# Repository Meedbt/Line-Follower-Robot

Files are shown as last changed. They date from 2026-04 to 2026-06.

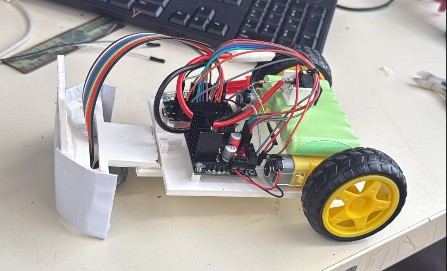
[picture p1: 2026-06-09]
RobotZEBI/assets/robot.jpg

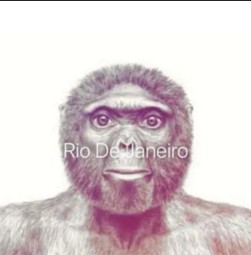
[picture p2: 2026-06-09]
RobotZEBI/assets/photoequipe.jpg

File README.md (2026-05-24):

# 🤖 Line Follower Robot — GEII BUT1

Robot autonome suiveur de ligne développé dans le cadre des **Rencontres de Robotique BUT GEII 2026** .

Projet réalisé en 1ère année de BUT GEII, en équipe de 3 étudiants.

## Matériel utilisé
- **Microcontrôleur :** ESP32
- **Capteur de ligne :** Pololu QTR-8A (8 capteurs IR)
- **Hacheur moteur :** L298N (Joy-IT SBC-MotoDriver2)
- **Moteurs :** 2× moteurs DC TT + roue folle
- **Détection barrière :** Capteur ultrason HC-SR04
- **Alimentation :** Batterie 12V

## Fonctionnalités
- Suivi de ligne par algorithme PID
- Interface web via Wi-Fi pour régler les paramètres PID en temps réel
- Gestion des lignes en pointillés et segments inversés (blanc sur noir)
- Arrêt automatique à l'arrivée via l'ultrason
- Marche arrière gérée

## Châssis
- Style châssis RC, cadre ouvert
- Imprimé en 3D (PLA), modélisé sur Fusion 360

## 1. Schéma de câblage


Capture d’écran 2026-04-15 215151

## 2. Modele 3D 


---
*IUT — BUT GEII 1ère année | Rencontres Robotique 2026*

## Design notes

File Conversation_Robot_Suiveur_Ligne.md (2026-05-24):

# Conversation Complete - Robot Suiveur De Ligne ESP32

Ce document resume toute la conversation et l'evolution du projet de robot suiveur de ligne: materiel, logique de suivi, interface, marqueurs, intersections, ultrason, batterie, challenges, parcours avance et nouvelle interface competition.

## 1. Materiel Et Objectif

Le projet principal utilise:

- ESP32
- QTR-8RC
- L298N
- deux moteurs DC
- capteur ultrason HC-SR04
- batterie NiMH 7.2V
- interface web embarquee

Objectif:

- suivre une ligne noire sur fond clair
- executer des challenges de robotique
- gerer les marqueurs et intersections
- detecter l'arrivee/barriere
- automatiser les missions via une interface simple

## 2. Code De Reference Initial

Le code de reference fourni au debut utilisait:

- `AFMotor.h`
- `QTRSensors.h`
- 5 capteurs
- un controleur PD

Principe du code original:

```cpp
position = qtrrc.readLine(sensors);
error = position - 2000;

motorSpeed = KP * error + KD * (error - lastError);
lastError = error;

leftMotorSpeed = baseSpeed + motorSpeed;
rightMotorSpeed = baseSpeed - motorSpeed;
```

Il ne pouvait pas etre repris directement car il etait fait pour un shield moteur Adafruit, pas pour un ESP32 avec L298N.

## 3. Pins Actuelles

Pins QTR-8RC, dans l'ordre physique gauche vers droite:

```cpp
const uint8_t BROCHES_CAPTEURS[NOMBRE_CAPTEURS] = {
  18, 25, 33, 32, 5, 4, 22, 23
};
```

Pins L298N:

```cpp
const uint8_t PWM_GAUCHE = 16;
const uint8_t GAUCHE_IN1 = 26;
const uint8_t GAUCHE_IN2 = 27;
const uint8_t PWM_DROITE = 19;
const uint8_t DROITE_IN1 = 14;
const uint8_t DROITE_IN2 = 12;
```

Pins ultrason:

```cpp
const uint8_t ULTRASON_TRIG = 21;
const uint8_t ULTRASON_ECHO = 13;
```

Pin batterie:

```cpp
const uint8_t BATTERIE_ADC = 35;
```

Notes importantes:

- GPIO34 et GPIO35 ne doivent pas etre utilises pour le QTR-8RC car ils sont entree uniquement.
- GPIO35 est par contre tres bien pour mesurer la batterie.
- Si le HC-SR04 est alimente en 5V, il faut un diviseur de tension sur `ECHO`.

## 4. Suivi De Ligne

La version ESP32 utilise:

```cpp
qtr.readLineBlack(valeursCapteurs);
```

Donc:

```text
0    = blanc
1000 = noir
```

Position:

```text
0    = ligne tout a gauche
3500 = ligne au centre
7000 = ligne tout a droite
```

Controle PD:

```cpp
erreur = position - 3500;
derivee = erreur - derniereErreur;
correction = kp * erreur + kd * derivee;

vitesseGauche = vitesseBase + correction;
vitesseDroite = vitesseBase - correction;
```

Reglages principaux:

```cpp
int vitesseBase = 135;
float kp = 0.075;
float kd = 0.45;
```

Reglage:

```text
Robot trop lent en virage  -> augmenter KP
Robot zigzague             -> augmenter KD ou baisser KP
Robot stable mais lent     -> augmenter vitesseBase
```

## 5. Ancienne Interface Web De Reglage

Une premiere interface web complete avait ete creee.

Elle permettait de regler:

- vitesse base
- KP
- KD
- mode arret marqueur
- nombre de marqueurs avant stop
- stop ultrason
- distance stop ultrason
- mode intersections
- sequence intersections
- parcours avance
- sequence aller
- sequence retour
- demi-tour apres marqueur/intersection
- pauses parking B/C
- arret final marqueur/intersection

Elle affichait:

- position
- erreur
- vitesses moteurs
- capteurs QTR
- marqueurs
- intersections
- ultrason
- batterie
- phase
- action

L'option `Correction inversee` a ete supprimee car elle ne servait pas.

## 6. Nouvelle Interface Competition

Une nouvelle interface simplifiee a ete creee pour le jour du challenge.

Elle remplace l'affichage de l'ancienne interface:

```cpp
serveur.send_P(200, "text/html", PAGE_COMPETITION);
```

L'ancienne interface `PAGE_WEB` est encore dans le code comme sauvegarde interne, mais elle n'est plus affichee.

Nouvelle interface:

- selection du challenge
- bouton `CALIBRER`
- bouton `START CHALLENGE`
- bouton `URGENCE STOP`
- challenge actif
- position ligne
- ultrason barriere
- batterie
- priorite droite
- marqueurs
- intersections
- phase
- etape/action actuelle

Wi-Fi:

```text
Nom : Robot Z.E.B.I
Mot de passe : 12345678
Adresse : http://192.168.4.1
```

## 7. Profils De Challenges

Les challenges sont maintenant pre-codes dans:

```cpp
const ChallengeConfig CHALLENGES[] = { ... };
```

Chaque challenge contient:

- nom
- arret marqueur oui/non
- cible marqueur
- stop ultrason oui/non
- distance stop
- mode intersections oui/non
- sequence simple
- parcours avance oui/non
- sequence aller
- sequence retour
- demi-tour apres marqueur
- demi-tour apres intersection
- pause B apres marqueur
- pause C apres marqueur
- arret final apres marqueur
- arret final apres intersection

Quand un challenge est selectionne:

```cpp
appliquerChallenge(numeroChallenge);
```

Le robot charge automatiquement la configuration correspondante.

## 8. Marqueurs Lateraux

Les petits tires noirs sur les cotes sont traites comme des marqueurs.

Capteurs utilises:

```text
valeursCapteurs[0] et [1] = cote gauche
valeursCapteurs[6] et [7] = cote droit
```

Un marqueur est compte si:

- le centre voit encore la ligne
- un capteur extreme voit du noir
- ce n'est pas une intersection
- le robot est actif
- le marqueur n'a pas deja ete compte

Le code evite de compter plusieurs fois le meme marqueur avec:

```cpp
marqueurDejaCompte
DELAI_ANTI_DOUBLE_MS
```

## 9. Difference Entre Marqueur Et Intersection

La difference se fait avec le nombre de capteurs noirs.

Marqueur:

```text
centre noir + extreme noir + peu de capteurs noirs
```

Intersection:

```text
beaucoup de capteurs noirs en meme temps
```

Seuil:

```cpp
const uint8_t NB_CAPTEURS_NOIRS_INTERSECTION = 5;
```

Donc:

```text
moins de 5 capteurs noirs -> possible marqueur
5 capteurs noirs ou plus  -> intersection, pas marqueur
```

## 10. Mode Arret Marqueur

Ce mode sert aux challenges ou le robot doit s'arreter a un endroit demande.

Principe:

```text
Mode arret marqueur = Oui
Marqueurs avant stop = N
Quand compteurMarqueurs >= N -> stop
```

En mode parcours avance, cet arret simple est ignore pour ne pas bloquer les aller-retour:

```cpp
if (modeArretMarqueur && !modeParcoursAvance && compteurMarqueurs >= cibleMarqueurs)
```

## 11. Ultrason Et Barriere

Le capteur ultrason detecte les barres d'arrivee.

Pins:

```cpp
const uint8_t ULTRASON_TRIG = 21;
const uint8_t ULTRASON_ECHO = 13;
```

Principe:

```text
Stop ultrason = Oui
Distance <= distanceStop
pendant 3 mesures d'affilee
=> stop
```

Pour faire tomber une barriere:

```text
Stop ultrason = Non
```

Pour eviter la barriere:

```text
Stop ultrason = Oui
Distance stop = environ 10 a 20 cm
```

## 12. Batterie NiMH 7.2V

La batterie est une NiMH 7.2V.

Tensions:

```text
pleine  : 8.4V
nominale: 7.2V
faible  : 6.0V
```

Montage pont diviseur:

```text
+ batterie
   |
  R1 = 100k
   |
   +---- GPIO35 ESP32
   |
  R2 = 47k
   |
GND batterie / GND ESP32
```

Constantes:

```cpp
const float BAT_R1 = 100000.0;
const float BAT_R2 = 47000.0;
const float BAT_TENSION_MAX = 8.4;
const float BAT_TENSION_MIN = 6.0;
const float BAT_CALIBRATION = 1.00;
```

Si l'affichage ne correspond pas au multimetre, ajuster:

```cpp
BAT_CALIBRATION
```

## 13. Gestion Des Intersections

Le mode intersections permet d'utiliser une sequence de decisions.

Lettres:

```text
S = tout droit
G = gauche
D = droite
```

Exemples valides:

```text
SSG
S,S,G
S D G
```

Le code nettoie automatiquement la sequence et ne garde que `S`, `G`, `D`.

Exemple:

```text
Sequence = SSG
```

Signifie:

```text
intersection 1 -> tout droit
intersection 2 -> tout droit
intersection 3 -> gauche
```

Si le robot voit plus d'intersections que la sequence, il repete la derniere decision.

Exemple:

```text
S,D
```

Donne:

```text
intersection 1 -> S
intersection 2 -> D
intersection 3 -> D
intersection 4 -> D
```

## 14. Parcours Avance

Le mode parcours avance sert pour les missions avec:

- aller
- demi-tour
- retour
- pauses parking
- arret final

Reglages:

```text
Parcours avance
Sequence aller
Sequence retour
Demi-tour apres marqueur
Demi-tour apres intersection
Pause B apres marqueur
Pause C apres marqueur
Arret final marqueur
Arret final intersection
```

Valeur `0`:

```text
desactive la fonction
```

## 15. Sequence Aller / Retour

Si:

```text
Parcours avance = Oui
Sequence aller = SSG
Sequence retour = vide
```

Alors la sequence retour est automatiquement nettoyee et devient:

```text
S
```

Mais le robot ne passe en phase retour que si un demi-tour est defini:

```text
Demi-tour apres marqueur > 0
ou
Demi-tour apres intersection > 0
```

Sans demi-tour, le robot reste en phase `Aller`.

## 16. Demi-Tour

Deux facons de declencher le demi-tour:

```text
Demi-tour apres marqueur
Demi-tour apres intersection
```

Exemple:

```text
Sequence aller = SSG
Demi-tour apres intersection = 3
Demi-tour apres marqueur = 0
```

Le robot:

```text
intersection 1 -> S
intersection 2 -> S
intersection 3 -> G
puis demi-tour
passe en phase Retour
```

Utiliser:

```text
Demi-tour apres intersection
```

si le point de demi-tour est lie a un croisement.

Utiliser:

```text
Demi-tour apres marqueur
```

si le point de demi-tour est lie a un petit tire lateral.

## 17. Arret Final

Les options:

```text
Arret final marqueur
Arret final intersection
```

servent seulement en phase `Retour`.

Arret final marqueur:

```text
en phase Retour, arrete-toi apres N marqueurs
```

Arret final intersection:

```text
en phase Retour, arrete-toi apres N intersections
```

Exemple:

```text
Arret final marqueur = 3
```

Le robot:

```text
Aller
Demi-tour
Retour
compte 3 marqueurs
Stop
```

Si les deux valent `0`, le robot ne s'arrete pas automatiquement apres le retour.

## 18. Pauses Parking

Pour le challenge 20, des pauses parking ont ete prevues:

```text
Pause B apres marqueur
Pause C apres marqueur
```

Quand le compteur de marqueurs atteint la valeur choisie:

```text
robot stop 5 secondes
puis reprend
```

Duree:

```cpp
const uint16_t DUREE_PAUSE_PARKING_MS = 5000;
```

## 19. Challenges Et Capacites

Le PDF des challenges a ete analyse.

### Challenges simples

Faisables avec le suivi simple:

```text
Challenge 1
Challenge 2
```

Reglage:

```text
Stop ultrason = Non
```

pour faire tomber la barriere.

### Stop a endroit demande

Faisables avec les marqueurs:

```text
Challenge 3
Challenge 4
```

Reglage:

```text
Mode arret marqueur = Oui
Marqueurs avant stop = N
```

### Pistes marquees

Partiellement gerees avec sequences d'intersections:

```text
Challenges 8, 9, 10, 11, 16
```

Il faut ajuster les sequences sur piste.

### Aller-retour / demi-tour

Des fonctions ont ete ajoutees pour:

```text
Challenges 5, 6, 7, 12, 13, 14, 15, 17, 18, 19
```

Mais les valeurs exactes doivent etre testees sur la piste.

### Challenge 20

Le code contient maintenant les pauses B/C:

```text
Pause B apres marqueur
Pause C apres marqueur
```

Les numeros de marqueurs doivent etre calibres sur piste.

## 20. Priorite A Droite

Le reglement mentionne:

```text
priorite a droite
```

Le robot actuel n'a pas encore de vraie detection laterale droite.

Avec l'ultrason frontal, il peut detecter un obstacle devant, mais pas vraiment appliquer la priorite a droite.

Decision:

```text
laisser cette partie pour plus tard
```

## 21. Idee Alternative Arduino Nano

Une idee alternative a ete discutee:

- Arduino Nano
- QTR-8RC
- hacheur moteur
- boutons
- ecran OLED
- pas d'interface web

Avantages:

- plus simple terrain
- pas de Wi-Fi
- plus rapide au demarrage
- plus robuste

Inconvenients:

- moins confortable pour regler
- moins de memoire
- interface OLED plus limitee

Cette piste a ete mise de cote pour revenir au programme ESP32.

## 22. Etat Actuel Du Fichier

Fichier actuel:

```text
C:\Users\mouha\Downloads\linefollowerV2.ino
```

Fonctions presentes:

- suivi ligne QTR
- controle moteur L298N
- interface competition
- profils de 20 challenges
- calibration
- start challenge
- urgence stop
- marqueurs
- intersections
- sequences S/G/D
- parcours avance
- phase aller/retour
- demi-tour
- pauses parking
- arret final
- ultrason barriere
- batterie

## 23. Points A Tester En Priorite

1. Compiler dans l'IDE Arduino.
2. Verifier que l'interface competition s'affiche.
3. Tester challenge 1 avec:

```text
Stop ultrason = Non dans le profil
```

4. Tester calibration QTR.
5. Tester position ligne autour de 3500.
6. Tester marqueurs.
7. Tester intersections avec une sequence simple.
8. Tester demi-tour.
9. Tester ultrason.
10. Ajuster les profils de challenges.

## 24. Compilation

Impossible de compiler depuis Codex car:

```text
arduino-cli n'est pas installe
```

La verification finale doit etre faite dans l'IDE Arduino.

Si une erreur apparait, envoyer le message exact pour correction.

## 25. Notes Importantes

Les profils `CHALLENGES[]` sont une base.

Pour les missions complexes:

- les sequences `S/G/D`
- les numeros de marqueurs
- les numeros d'intersections
- les pauses
- les arrets finaux

doivent etre ajustes sur la vraie piste.

Le code est maintenant oriente competition:

```text
selectionner challenge
calibrer
start
urgence stop si besoin
```

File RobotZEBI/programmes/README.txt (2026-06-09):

Place ici les programmes finaux utilises par le robot :

- Missions_0-20.ino
- Missions_21-22.ino
- Mission_23.ino
- autres versions si necessaire

La page programmes.html contient deja les liens vers ces fichiers.

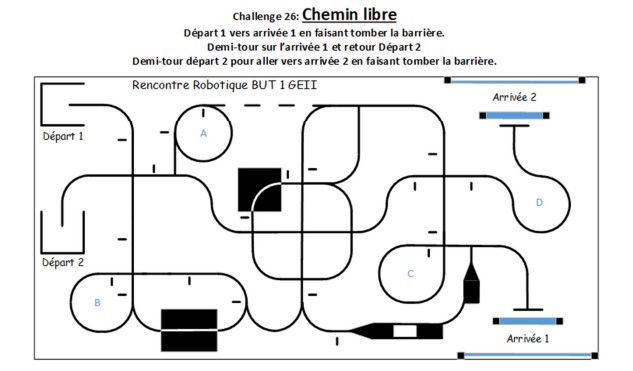
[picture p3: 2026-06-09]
RobotZEBI/assets/piste3.jpg

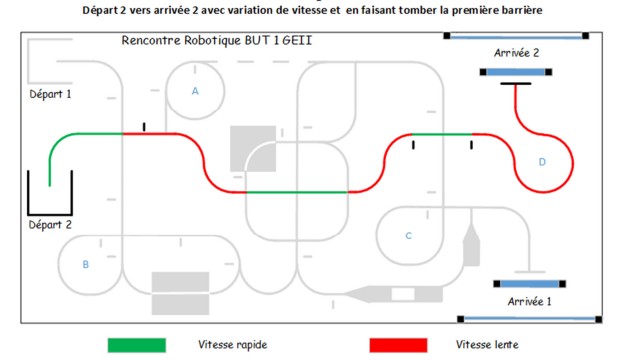
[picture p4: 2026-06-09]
RobotZEBI/assets/piste1.jpg

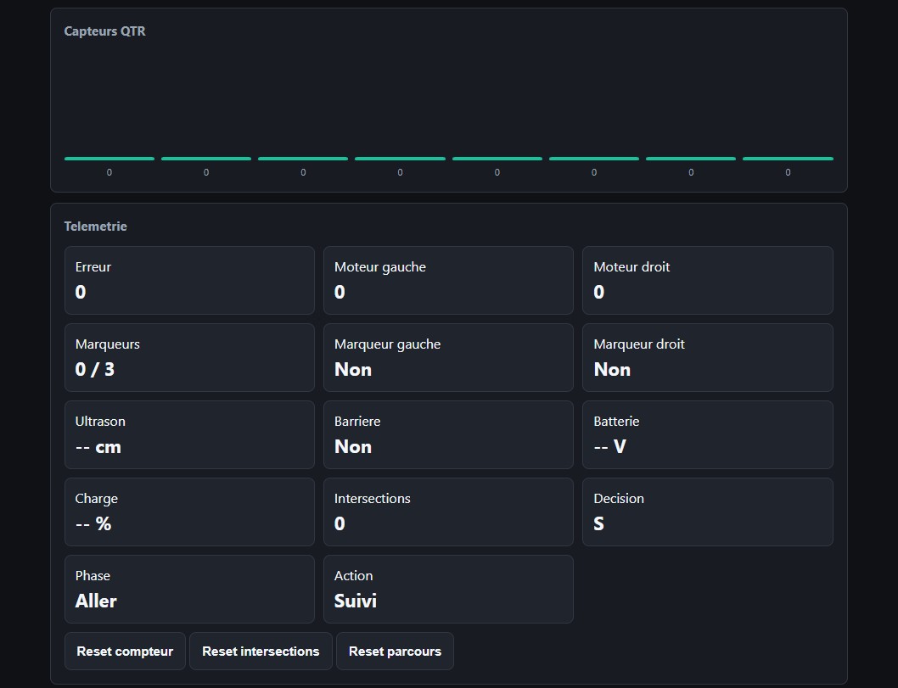
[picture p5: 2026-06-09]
RobotZEBI/assets/interfaceweb.jpg

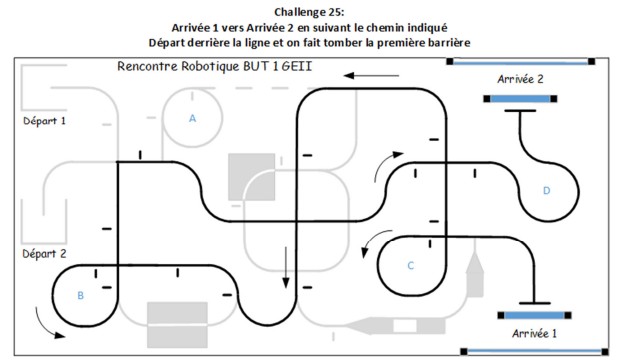
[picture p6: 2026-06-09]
RobotZEBI/assets/piste2.jpg

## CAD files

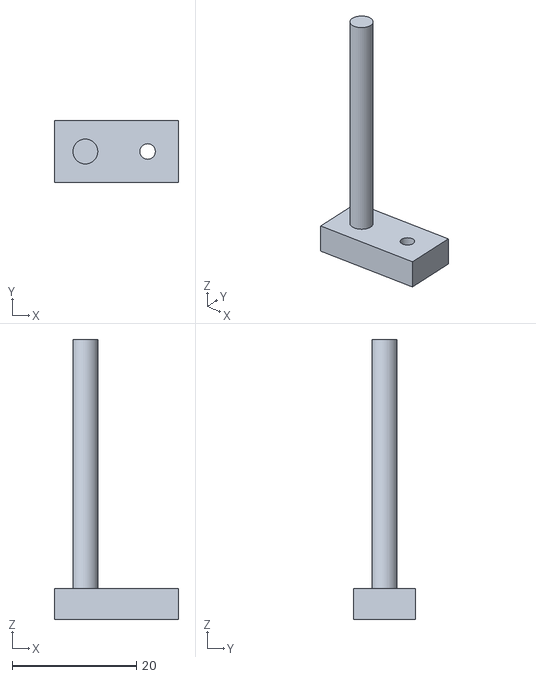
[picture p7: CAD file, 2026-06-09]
SupportCapteur.stl
20.0 x 10.0 x 45.0

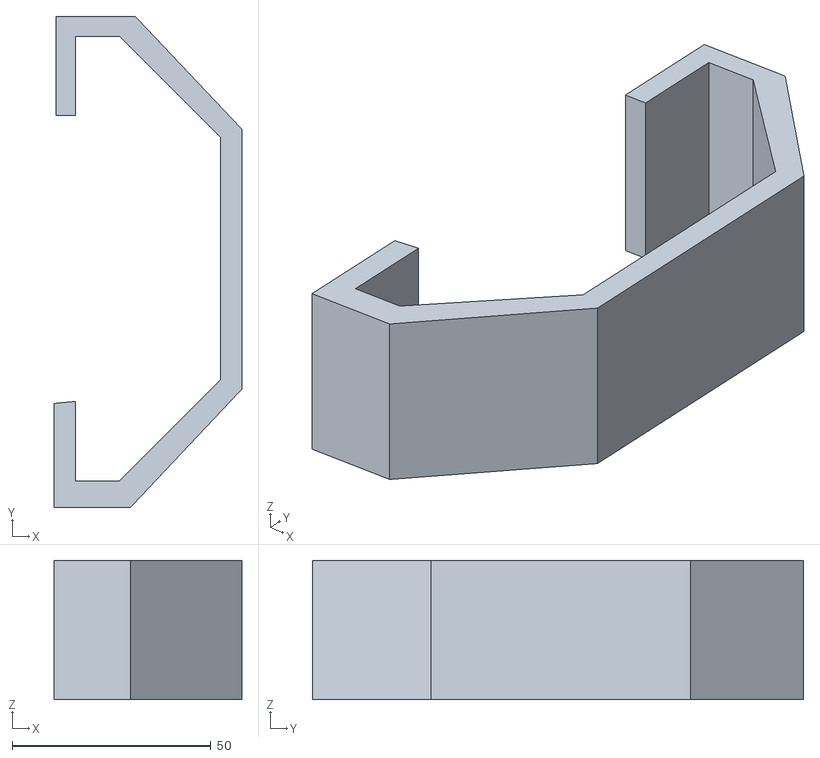
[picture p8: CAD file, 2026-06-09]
cacheMoteur.stl
47.3 x 123.6 x 35.0

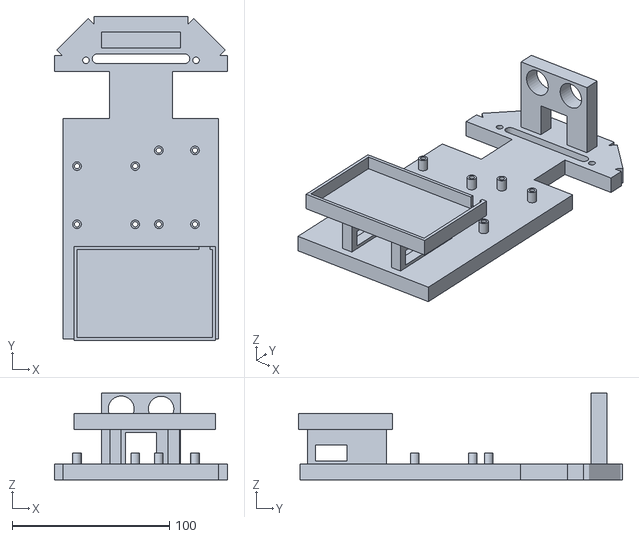
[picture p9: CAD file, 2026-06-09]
ChasisRobot.stl
110.0 x 206.2 x 55.0

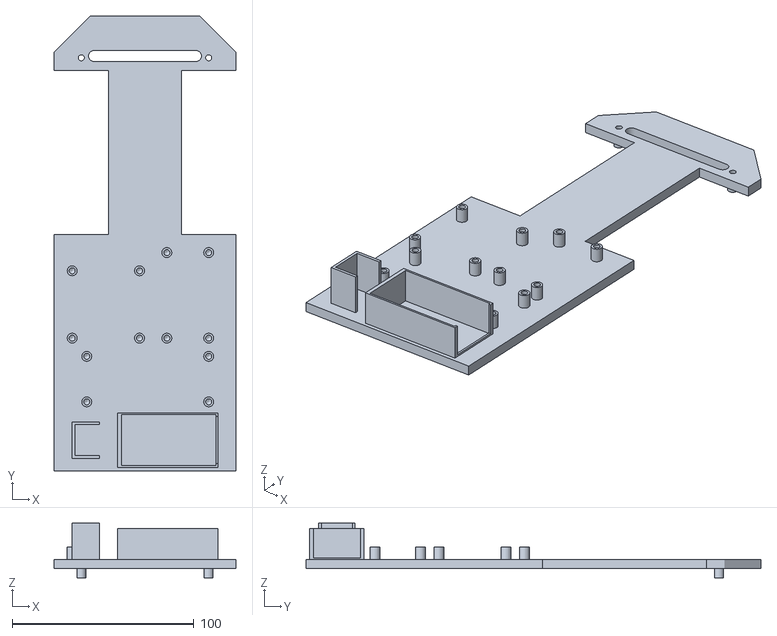
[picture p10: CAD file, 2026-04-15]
Robot004.stl
100.0 x 250.0 x 30.0

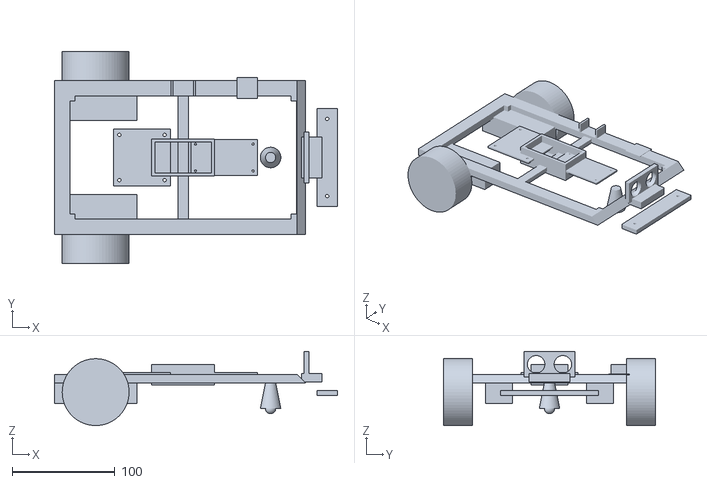
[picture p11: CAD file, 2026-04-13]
Robot002l.stl
275.0 x 206.0 x 72.0

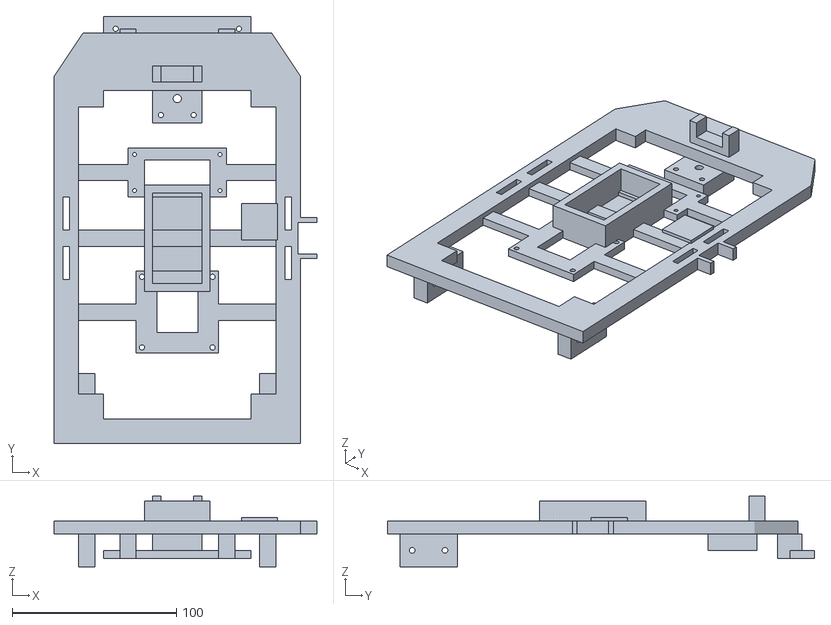
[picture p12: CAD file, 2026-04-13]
Robot001.stl
160.0 x 260.0 x 43.0

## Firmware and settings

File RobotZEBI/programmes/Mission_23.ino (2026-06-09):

#include <Arduino.h>
#include <QTRSensors.h>
#include <WiFi.h>
#include <WebServer.h>
#include <Preferences.h>

QTRSensors qtr;
WebServer serveur(80);
Preferences preferences;

const uint8_t NOMBRE_CAPTEURS = 8;

// Ordre physique des capteurs QTR de gauche a droite.
// La position lue va de 0 a 7000, avec 3500 au centre.
const uint8_t BROCHES_CAPTEURS[NOMBRE_CAPTEURS] = {
  18, 25, 33, 32, 5, 4, 22, 23
  
};

// Broche LEDON/CTRL du QTR.
// Laisse -1 si cette broche n'est pas connectee.
const int8_t BROCHE_EMETTEUR = -1;

// Broches du L298N.
const uint8_t PWM_GAUCHE = 16;   // L298N ENA
const uint8_t GAUCHE_IN1 = 26;   // L298N IN1
const uint8_t GAUCHE_IN2 = 27;   // L298N IN2
const uint8_t PWM_DROITE = 19;   // L298N ENB
const uint8_t DROITE_IN1 = 14;   // L298N IN3
const uint8_t DROITE_IN2 = 12;   // L298N IN4

// Capteur ultrason HC-SR04 pour detecter les barres d'arrivee.
// Important: ECHO sort souvent en 5V, mets un diviseur de tension vers l'ESP32.
const uint8_t ULTRASON_TRIG = 21;
const uint8_t ULTRASON_ECHO = 13;

// Mesure batterie NiMH 7.2V via pont diviseur:
// + batterie -> R1 100k -> GPIO35 -> R2 47k -> GND commun.
const uint8_t BATTERIE_ADC = 34;
const float BAT_R1 = 100000.0;
const float BAT_R2 = 47000.0;
const float BAT_TENSION_MAX = 8.4;
const float BAT_TENSION_MIN = 6.0;
const float BAT_CALIBRATION = 1.00;

// Reglages moteur/PID: commence doucement, puis augmente petit a petit. 
// Si le robot est stable mais trop lent : augmente VITESSE_BASE petit à petit, par exemple 145, puis 155, etc.
int vitesseBase = 135;
const int VITESSE_MIN = 0;
const int VITESSE_MAX = 230;

// KP corrige l'ecart a la ligne, KD calme les oscillations.
// Si le robot reagit trop lentement: augmente KP. S'il zigzague: augmente KD ou baisse KP.
// Si le robot réagit trop lentement aux virages : augmente un peu KP.
// Si le robot zigzague/oscille : augmente un peu KD, ou baisse KP.
float kp = 0.075;
float kd = 0.45;

const bool INVERSER_MOTEUR_GAUCHE = false;
const bool INVERSER_MOTEUR_DROITE = false;

const uint16_t QTR_TIMEOUT_US = 2500;
const uint16_t SEUIL_LIGNE_PERDUE = 120;
const bool DEBUG = true;

uint16_t valeursCapteurs[NOMBRE_CAPTEURS];
int derniereErreur = 0;
int dernierePosition = 3500;
int derniereVitesseGauche = 0;
int derniereVitesseDroite = 0;
bool robotActif = false;
bool derniereLigneDetectee = false;
bool modeArretMarqueur = false;
bool marqueurDejaCompte = false;
bool marqueurGaucheActif = false;
bool marqueurDroiteActif = false;
bool stopUltrasonActif = false;
bool barriereDetecteeUltrason = false;
bool modeIntersections = false;
bool intersectionDetectee = false;
bool intersectionDejaComptee = false;
bool actionIntersectionActive = false;
bool modeParcoursAvance = false;
bool phaseRetour = false;
bool demiTourActif = false;
bool pauseParkingActive = false;
bool modePauseMarqueur = false;
bool pauseMarqueurActive = false;
bool pauseBDejaFaite = false;
bool pauseCDejaFaite = false;
int compteurMarqueurs = 0;
int cibleMarqueurs = 3;
int compteurIntersections = 0;
int demiTourApresMarqueur = 0;
int demiTourApresIntersection = 0;
int pauseBApresMarqueur = 0;
int pauseCApresMarqueur = 0;
int arretFinalApresMarqueur = 0;
int arretFinalApresIntersection = 0;
int distanceStopCm = 15;
int distanceUltrasonCm = 999;
float tensionBatterie = 0.0;
int pourcentageBatterie = 0;
String sequenceIntersections = "S";
String sequenceAller = "S";
String sequenceRetour = "S";
char decisionIntersection = 'S';
uint32_t dernierMarqueurMs = 0;
uint32_t derniereMesureUltrasonMs = 0;
uint32_t derniereMesureBatterieMs = 0;
uint32_t debutActionIntersectionMs = 0;
uint32_t debutDemiTourMs = 0;
uint32_t debutPauseParkingMs = 0;
uint32_t debutPauseMarqueurMs = 0;
uint8_t confirmationsUltrason = 0;
uint8_t confirmationsBarriereTombee = 0;

const uint16_t SEUIL_MARQUEUR = 650;
const uint16_t SEUIL_CENTRE_LIGNE = 180;
const uint8_t NB_CAPTEURS_NOIRS_INTERSECTION = 5;
const uint16_t DELAI_ANTI_DOUBLE_MS = 250;
const uint8_t CONFIRMATIONS_STOP_ULTRASON = 3;
const uint8_t CONFIRMATIONS_BARRIERE_TOMBEE = 5;
const uint16_t PERIODE_ULTRASON_MS = 60;
const uint16_t PERIODE_BATTERIE_MS = 500;
const uint16_t SEUIL_INTERSECTION = 650;
const uint8_t NB_CAPTEURS_NOIRS_INTERSECTION_ACTIVE = 5;
const uint8_t NB_CAPTEURS_NOIRS_SORTIE_INTERSECTION = 2;
const int VITESSE_ACTION_INTERSECTION = 115;
const uint16_t DUREE_TOUT_DROIT_INTERSECTION_MS = 180;
const uint16_t DUREE_MIN_ROTATION_INTERSECTION_MS = 180;
const uint16_t DUREE_MAX_ROTATION_INTERSECTION_MS = 950;
const int VITESSE_DEMI_TOUR = 120;
const uint16_t DUREE_MIN_DEMI_TOUR_MS = 700;
const uint16_t DUREE_MAX_DEMI_TOUR_MS = 2200;
const uint16_t DUREE_PAUSE_PARKING_MS = 5000;
uint16_t dureePauseMarqueurMs = 2000;

const char* NOM_WIFI = "Robot Z.E.B.I";
const char* MOT_DE_PASSE_WIFI = "12345678";

const char PAGE_WEB[] PROGMEM = R"HTML(
<!doctype html>
<html lang="fr">
<head>
  <meta charset="utf-8">
  <meta name="viewport" content="width=device-width, initial-scale=1">
  <title>LineFollower ESP32</title>
  <style>
    :root {
      color-scheme: dark;
      --bg: #0f1115;
      --panel: #181b22;
      --panel-2: #20242d;
      --text: #f4f7fb;
      --muted: #9aa4b2;
      --line: #303642;
      --accent: #18c29c;
      --danger: #ff5d5d;
      --warn: #f2b84b;
    }
    * { box-sizing: border-box; }
    body {
      margin: 0;
      min-height: 100vh;
      background: var(--bg);
      color: var(--text);
      font-family: system-ui, -apple-system, BlinkMacSystemFont, "Segoe UI", sans-serif;
    }
    main {
      width: min(980px, 100%);
      margin: 0 auto;
      padding: 20px;
    }
    header {
      display: flex;
      justify-content: space-between;
      align-items: center;
      gap: 16px;
      margin-bottom: 18px;
    }
    h1 {
      margin: 0;
      font-size: 26px;
      font-weight: 750;
      letter-spacing: 0;
    }
    .status {
      padding: 8px 12px;
      border: 1px solid var(--line);
      border-radius: 8px;
      color: var(--muted);
      background: var(--panel);
      white-space: nowrap;
    }
    .grid {
      display: grid;
      grid-template-columns: repeat(12, 1fr);
      gap: 12px;
    }
    .card {
      grid-column: span 6;
      background: var(--panel);
      border: 1px solid var(--line);
      border-radius: 8px;
      padding: 16px;
    }
    .card.wide { grid-column: span 12; }
    h2 {
      margin: 0 0 14px;
      font-size: 15px;
      color: var(--muted);
      font-weight: 650;
    }
    .big {
      font-size: 42px;
      font-weight: 800;
      line-height: 1;
    }
    .sub {
      margin-top: 6px;
      color: var(--muted);
      font-size: 14px;
    }
    .buttons {
      display: grid;
      grid-template-columns: repeat(2, 1fr);
      gap: 10px;
    }
    button {
      border: 0;
      border-radius: 8px;
      padding: 13px 14px;
      color: #07110f;
      background: var(--accent);
      font-weight: 750;
      font-size: 15px;
      cursor: pointer;
    }
    button.secondary {
      color: var(--text);
      background: var(--panel-2);
      border: 1px solid var(--line);
    }
    button.danger {
      color: #170606;
      background: var(--danger);
    }
    label {
      display: grid;
      gap: 8px;
      margin: 14px 0;
      color: var(--muted);
      font-size: 14px;
    }
    .row {
      display: flex;
      justify-content: space-between;
      align-items: center;
      gap: 12px;
    }
    output {
      color: var(--text);
      font-variant-numeric: tabular-nums;
    }
    input[type="range"] {
      width: 100%;
      accent-color: var(--accent);
    }
    input[type="text"] {
      width: 100%;
      border: 1px solid var(--line);
      border-radius: 8px;
      padding: 11px 12px;
      color: var(--text);
      background: var(--panel-2);
      font: inherit;
      text-transform: uppercase;
    }
    .sensors {
      display: grid;
      grid-template-columns: repeat(8, 1fr);
      gap: 8px;
      align-items: end;
      height: 150px;
    }
    .sensor {
      min-width: 0;
      display: grid;
      align-content: end;
      gap: 6px;
      height: 100%;
    }
    .bar {
      min-height: 4px;
      border-radius: 6px 6px 2px 2px;
      background: var(--accent);
    }
    .sensor span {
      color: var(--muted);
      font-size: 11px;
      text-align: center;
      overflow-wrap: anywhere;
    }
    .metrics {
      display: grid;
      grid-template-columns: repeat(3, 1fr);
      gap: 10px;
    }
    .metric {
      background: var(--panel-2);
      border: 1px solid var(--line);
      border-radius: 8px;
      padding: 12px;
    }
    .metric strong {
      display: block;
      margin-top: 4px;
      font-size: 22px;
      font-variant-numeric: tabular-nums;
    }
    @media (max-width: 720px) {
      main { padding: 14px; }
      header { align-items: flex-start; flex-direction: column; }
      .card, .card.wide { grid-column: span 12; }
      .metrics { grid-template-columns: 1fr; }
      .buttons { grid-template-columns: 1fr; }
      .big { font-size: 36px; }
    }
  </style>
</head>
<body>
  <main>
    <header>
      <h1>LineFollower ESP32 - Mission 23</h1>
      <div class="status" id="etat">Connexion...</div>
    </header>

    <section class="grid">
      <article class="card">
        <h2>Position ligne</h2>
        <div class="big" id="position">3500</div>
        <div class="sub">Centre ideal: 3500</div>
      </article>

      <article class="card">
        <h2>Commandes</h2>
        <div class="buttons">
          <button id="startStop" onclick="toggleRobot()">Start</button>
          <button class="secondary" onclick="calibrer()">Calibrer</button>
          <button class="secondary" onclick="sauver()">Sauvegarder</button>
          <button class="danger" onclick="stopRobot()">Stop</button>
        </div>
      </article>

      <article class="card wide">
        <h2>Reglages</h2>
        <label>
          <div class="row"><span>Vitesse base</span><output id="baseOut">135</output></div>
          <input id="base" type="range" min="60" max="230" step="1" value="135" oninput="majReglages()">
        </label>
        <label>
          <div class="row"><span>KP</span><output id="kpOut">0.075</output></div>
          <input id="kp" type="range" min="0" max="0.300" step="0.001" value="0.075" oninput="majReglages()">
        </label>
        <label>
          <div class="row"><span>KD</span><output id="kdOut">0.450</output></div>
          <input id="kd" type="range" min="0" max="1.500" step="0.005" value="0.450" oninput="majReglages()">
        </label>
        <label>
          <div class="row"><span>Mode arret marqueur</span><output id="modeOut">Non</output></div>
          <input id="mode" type="range" min="0" max="1" step="1" value="0" oninput="majReglages()">
        </label>
        <label>
          <div class="row"><span>Pause a chaque marqueur</span><output id="pauseMarkOut">Non</output></div>
          <input id="pauseMark" type="range" min="0" max="1" step="1" value="0" oninput="majReglages()">
        </label>
        <label>
          <div class="row"><span>Duree pause marqueur</span><output id="pauseMarkMsOut">2000 ms</output></div>
          <input id="pauseMarkMs" type="range" min="500" max="5000" step="100" value="2000" oninput="majReglages()">
        </label>
        <label>
          <div class="row"><span>Marqueurs avant stop</span><output id="targetOut">3</output></div>
          <input id="target" type="range" min="1" max="30" step="1" value="3" oninput="majReglages()">
        </label>
        <label>
          <div class="row"><span>Arrivee ultrason</span><output id="usOut">Non</output></div>
          <input id="us" type="range" min="0" max="1" step="1" value="0" oninput="majReglages()">
        </label>
        <label>
          <div class="row"><span>Distance detection barriere</span><output id="usDistOut">15 cm</output></div>
          <input id="usDist" type="range" min="5" max="40" step="1" value="15" oninput="majReglages()">
        </label>
        <label>
          <div class="row"><span>Mode intersections</span><output id="interOut">Non</output></div>
          <input id="inter" type="range" min="0" max="1" step="1" value="0" oninput="majReglages()">
        </label>
        <label>
          <div class="row"><span>Sequence intersections</span><output id="seqOut">S</output></div>
          <input id="seq" type="text" value="S" maxlength="100" oninput="majReglages()">
        </label>
        <label>
          <div class="row"><span>Parcours avance</span><output id="advOut">Non</output></div>
          <input id="adv" type="range" min="0" max="1" step="1" value="0" oninput="majReglages()">
        </label>
        <label>
          <div class="row"><span>Sequence aller</span><output id="seqGoOut">S</output></div>
          <input id="seqGo" type="text" value="S" maxlength="100" oninput="majReglages()">
        </label>
        <label>
          <div class="row"><span>Sequence retour</span><output id="seqBackOut">S</output></div>
          <input id="seqBack" type="text" value="S" maxlength="100" oninput="majReglages()">
        </label>
        <label>
          <div class="row"><span>Demi-tour apres marqueur</span><output id="uMarkOut">0</output></div>
          <input id="uMark" type="range" min="0" max="20" step="1" value="0" oninput="majReglages()">
        </label>
        <label>
          <div class="row"><span>Demi-tour apres intersection</span><output id="uInterOut">0</output></div>
          <input id="uInter" type="range" min="0" max="30" step="1" value="0" oninput="majReglages()">
        </label>
        <label>
          <div class="row"><span>Pause B apres marqueur</span><output id="parkBOut">0</output></div>
          <input id="parkB" type="range" min="0" max="20" step="1" value="0" oninput="majReglages()">
        </label>
        <label>
          <div class="row"><span>Pause C apres marqueur</span><output id="parkCOut">0</output></div>
          <input id="parkC" type="range" min="0" max="20" step="1" value="0" oninput="majReglages()">
        </label>
        <label>
          <div class="row"><span>Arret final marqueur</span><output id="finalMarkOut">0</output></div>
          <input id="finalMark" type="range" min="0" max="20" step="1" value="0" oninput="majReglages()">
        </label>
        <label>
          <div class="row"><span>Arret final intersection</span><output id="finalInterOut">0</output></div>
          <input id="finalInter" type="range" min="0" max="30" step="1" value="0" oninput="majReglages()">
        </label>
      </article>

      <article class="card wide">
        <h2>Capteurs QTR</h2>
        <div class="sensors" id="sensors"></div>
      </article>

      <article class="card wide">
        <h2>Telemetrie</h2>
        <div class="metrics">
          <div class="metric">Erreur<strong id="erreur">0</strong></div>
          <div class="metric">Moteur gauche<strong id="vg">0</strong></div>
          <div class="metric">Moteur droit<strong id="vd">0</strong></div>
          <div class="metric">Marqueurs<strong id="marks">0 / 3</strong></div>
          <div class="metric">Marqueur gauche<strong id="mg">Non</strong></div>
          <div class="metric">Marqueur droit<strong id="md">Non</strong></div>
          <div class="metric">Pause marqueur<strong id="pauseMarkState">Non</strong></div>
          <div class="metric">Ultrason<strong id="usNow">-- cm</strong></div>
          <div class="metric">Barriere<strong id="usState">Non</strong></div>
          <div class="metric">Batterie<strong id="batVolt">-- V</strong></div>
          <div class="metric">Charge<strong id="batPct">-- %</strong></div>
          <div class="metric">Intersections<strong id="interCount">0</strong></div>
          <div class="metric">Decision<strong id="interDecision">S</strong></div>
          <div class="metric">Phase<strong id="phaseNow">Aller</strong></div>
          <div class="metric">Action<strong id="actionNow">Suivi</strong></div>
        </div>
        <div style="margin-top:10px">
          <button class="secondary" onclick="resetCompteur()">Reset compteur</button>
          <button class="secondary" onclick="resetIntersections()">Reset intersections</button>
          <button class="secondary" onclick="resetParcours()">Reset parcours</button>
        </div>
      </article>
    </section>
  </main>

  <script>
    const sensors = document.getElementById('sensors');
    let envoiTimer = null;

    for (let i = 0; i < 8; i++) {
      sensors.insertAdjacentHTML('beforeend', `<div class="sensor"><div class="bar" id="b${i}"></div><span id="s${i}">0</span></div>`);
    }

    function valeur(id) {
      return document.getElementById(id).value;
    }

    function majLabels() {
      baseOut.value = valeur('base');
      kpOut.value = Number(valeur('kp')).toFixed(3);
      kdOut.value = Number(valeur('kd')).toFixed(3);
      modeOut.value = valeur('mode') === '1' ? 'Oui' : 'Non';
      pauseMarkOut.value = valeur('pauseMark') === '1' ? 'Oui' : 'Non';
      pauseMarkMsOut.value = `${valeur('pauseMarkMs')} ms`;
      targetOut.value = valeur('target');
      usOut.value = valeur('us') === '1' ? 'Oui' : 'Non';
      usDistOut.value = `${valeur('usDist')} cm`;
      interOut.value = valeur('inter') === '1' ? 'Oui' : 'Non';
      seqOut.value = valeur('seq').toUpperCase() || 'S';
      advOut.value = valeur('adv') === '1' ? 'Oui' : 'Non';
      seqGoOut.value = valeur('seqGo').toUpperCase() || 'S';
      seqBackOut.value = valeur('seqBack').toUpperCase() || 'S';
      uMarkOut.value = valeur('uMark');
      uInterOut.value = valeur('uInter');
      parkBOut.value = valeur('parkB');
      parkCOut.value = valeur('parkC');
      finalMarkOut.value = valeur('finalMark');
      finalInterOut.value = valeur('finalInter');
    }

    function majReglages() {
      majLabels();
      clearTimeout(envoiTimer);
      envoiTimer = setTimeout(() => {
        fetch(`/set?base=${valeur('base')}&kp=${valeur('kp')}&kd=${valeur('kd')}&mode=${valeur('mode')}&pauseMark=${valeur('pauseMark')}&pauseMarkMs=${valeur('pauseMarkMs')}&target=${valeur('target')}&us=${valeur('us')}&usDist=${valeur('usDist')}&inter=${valeur('inter')}&seq=${encodeURIComponent(valeur('seq'))}&adv=${valeur('adv')}&seqGo=${encodeURIComponent(valeur('seqGo'))}&seqBack=${encodeURIComponent(valeur('seqBack'))}&uMark=${valeur('uMark')}&uInter=${valeur('uInter')}&parkB=${valeur('parkB')}&parkC=${valeur('parkC')}&finalMark=${valeur('finalMark')}&finalInter=${valeur('finalInter')}`);
      }, 120);
    }

    function toggleRobot() {
      fetch('/toggle').then(lireEtat);
    }

    function stopRobot() {
      fetch('/stop').then(lireEtat);
    }

    function calibrer() {
      etat.textContent = 'Calibration...';
      fetch('/calibrate').then(lireEtat);
    }

    function sauver() {
      fetch('/save').then(() => {
        etat.textContent = 'Reglages sauvegardes';
      });
    }

    function resetCompteur() {
      fetch('/resetCount').then(lireEtat);
    }

    function resetIntersections() {
      fetch('/resetIntersections').then(lireEtat);
    }

    function resetParcours() {
      fetch('/resetCourse').then(lireEtat);
    }

    function appliquer(data) {
      position.textContent = data.position;
      erreur.textContent = data.error;
      vg.textContent = data.left;
      vd.textContent = data.right;
      etat.textContent = data.active ? 'Robot actif' : 'Robot stop';
      startStop.textContent = data.active ? 'Pause' : 'Start';
      startStop.className = data.active ? 'danger' : '';
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
void loop()
{
  serveur.handleClient();
  mettreAJourUltrason();
  mettreAJourBatterie();

  // Ligne noire sur fond clair. Si tu suis une ligne blanche, utilise readLineWhite().
  uint16_t position = qtr.readLineBlack(valeursCapteurs);
  dernierePosition = position;
  derniereLigneDetectee = ligneDetectee();
  detecterIntersections();
  detecterMarqueurs();

  if (!robotActif) {
    arreterMoteurs();
    return;
  }

  if (modeArretMarqueur && !modeParcoursAvance && compteurMarqueurs >= cibleMarqueurs) {
    robotActif = false;
    arreterMoteurs();
    return;
  }

  if (stopUltrasonActif && barriereDetecteeUltrason &&
      confirmationsBarriereTombee >= CONFIRMATIONS_BARRIERE_TOMBEE) {
    robotActif = false;
    arreterMoteurs();
    return;
  }

  gererParcoursAvance();

  if (!robotActif) {
    return;
  }
  if (executerPauseParking()) {
    return;
  }

  if (executerPauseMarqueur()) {
    return;
  }

  if (executerDemiTour()) {
    return;
  }

  if (executerActionIntersection()) {
    return;
  }

  if (!derniereLigneDetectee) {
    // Recherche simple: tourner du cote ou la ligne a ete vue en dernier.
    int sensRecherche = dernierePosition < 3500 ? -1 : 1;
    derniereVitesseGauche = 90 * sensRecherche;
    derniereVitesseDroite = -90 * sensRecherche;
    reglerMoteurs(derniereVitesseGauche, derniereVitesseDroite);
    return;
  }

  int erreur = (int)position - 3500;
  int derivee = erreur - derniereErreur;
  derniereErreur = erreur;

  // Meme logique que le code de reference: correction = KP * erreur + KD * variation.
  int correction = (int)(kp * erreur + kd * derivee);

  int vitesseGauche = vitesseBase + correction;
  int vitesseDroite = vitesseBase - correction;
  derniereVitesseGauche = constrain(vitesseGauche, -VITESSE_MAX, VITESSE_MAX);
  derniereVitesseDroite = constrain(vitesseDroite, -VITESSE_MAX, VITESSE_MAX);

  reglerMoteurs(vitesseGauche, vitesseDroite);

  if (DEBUG) {  
    static uint32_t dernierAffichage = 0;
    if (millis() - dernierAffichage > 100) {
      dernierAffichage = millis();
      Serial.print("pos=");
      Serial.print(position);
      Serial.print(" err=");
      Serial.print(erreur);
      Serial.print(" L=");
      Serial.print(vitesseGauche);
      Serial.print(" R=");
      Serial.println(vitesseDroite);
    }
  }
}

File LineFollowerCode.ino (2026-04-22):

#include <WiFi.h>
#include <ESPAsyncWebServer.h>
#include <QTRSensors.h>

// --- CONFIGURATION PINS ---
const int IN1 = 26; const int IN2 = 27; // Moteur Gauche
const int IN3 = 14; const int IN4 = 12; // Moteur Droit
const int ENA = 25; const int ENB = 28; // PWM Vitesse
const int LED_INIT = 13;    // LED Initialisation
const int LED_RUNNING = 10; // LED Pilotage actif

// --- PARAMÈTRES PID & VITESSE ---
float Kp = 0.4; 
float Kd = 1.2;
int lastError = 0;
int baseSpeed = 160;
volatile bool robotStop = false;      // Arrêt d'urgence
volatile bool robotForward = true;    // Direction: true=avant, false=arrière
uint16_t lastPosition = 3500;         // Dernière position capteur
unsigned long lastMovementTime = 0;   // Timestamp du dernier mouvement
bool ledBlinking = false;             // État LED clignotante

// --- OBJETS ---
QTRSensors qtr;
const uint8_t SensorCount = 8;
uint16_t sensorValues[SensorCount];
AsyncWebServer server(80);

// --- INTERFACE WEB (Stockée en Flash) ---
const char index_html[] PROGMEM = R"rawliteral(
<!DOCTYPE HTML><html><head><title>ZEBI Robot Control</title>
<meta name="viewport" content="width=device-width, initial-scale=1">
<style>
  * { margin: 0; padding: 0; box-sizing: border-box; }
  body { font-family: Arial, sans-serif; background: #1a1a1a; color: #fff; padding: 10px; }
  .container { max-width: 500px; margin: 0 auto; }
  h1 { text-align: center; margin: 20px 0; font-size: 28px; }
  .status { text-align: center; padding: 15px; background: #222; border-radius: 8px; margin-bottom: 20px; font-size: 14px; }
  .status.running { background: #1a5c1a; }
  .status.stopped { background: #5c1a1a; }
  
  .button-group { display: grid; grid-template-columns: 1fr 1fr; gap: 10px; margin-bottom: 20px; }
  .btn { padding: 15px; border: none; border-radius: 8px; font-size: 16px; font-weight: bold; cursor: pointer; transition: all 0.3s; }
  .btn-stop { background: #ff3333; color: white; grid-column: 1 / -1; font-size: 24px; padding: 30px; }
  .btn-stop:active { background: #cc0000; transform: scale(0.95); }
  .btn-start { background: #33a833; color: white; }
  .btn-start:active { background: #228022; }
  
  .control-group { background: #222; padding: 20px; border-radius: 8px; margin-bottom: 15px; }
  .control-group h3 { font-size: 14px; margin-bottom: 10px; text-transform: uppercase; color: #aaa; }
  
  label { display: block; margin-bottom: 5px; font-size: 13px; }
  input[type="range"] { width: 100%; height: 8px; cursor: pointer; accent-color: #ff6600; }
  input[type="number"] { width: 70px; padding: 5px; background: #333; color: #fff; border: 1px solid #444; border-radius: 4px; }
  
  .value { display: inline-block; margin-left: 10px; background: #333; padding: 3px 8px; border-radius: 4px; font-size: 13px; }
  .info { font-size: 12px; color: #999; margin-top: 20px; text-align: center; }
</style></head>
<body>
  <div class="container">
    <h1>🤖 ZEBI Robot</h1>
    
    <div class="status running" id="status">Statut: PRÊT</div>
    
    <div class="button-group">
      <button class="btn btn-stop" onclick="stopRobot()">🛑 ARRÊT D'URGENCE</button>
      <button class="btn btn-start" onclick="startRobot()">▶ DÉMARRER</button>
    </div>
    
    <div class="control-group">
      <h3>PID Contrôle</h3>
      <label>Kp (Proportionnel): <span class="value" id="kpVal">0.4</span></label>
      <input type="range" id="kp" min="0" max="2" step="0.1" value="0.4" oninput="updateKp()">
      
      <label style="margin-top: 15px;">Kd (Dérivée): <span class="value" id="kdVal">1.2</span></label>
      <input type="range" id="kd" min="0" max="3" step="0.1" value="1.2" oninput="updateKd()">
    </div>
    
    <div class="control-group">
      <h3>Vitesse</h3>
      <label>Vitesse de base: <span class="value" id="spVal">160</span></label>
      <input type="range" id="sp" min="50" max="255" step="5" value="160" oninput="updateSpeed()">
    </div>
    
    <div class="info">
      📡 Connecté à Robot-Z.E.B.I<br>
      IP: 192.168.4.1<br>
      Appuie longtemps sur ARRÊT EN CAS D'URGENCE
    </div>
  </div>

  <script>
    let isStopped = false;
    
    async function fetchAPI(endpoint) {
      try {
        await fetch('/' + endpoint);
      } catch(e) { console.log(e); }
    }
    
    function stopRobot() {
      document.getElementById('status').textContent = '🔴 ARRÊTÉ D\'URGENCE';
      document.getElementById('status').className = 'status stopped';
      isStopped = true;
      fetchAPI('stop');
    }
    
    function startRobot() {
      document.getElementById('status').textContent = '🟢 EN COURS D\'EXÉCUTION';
      document.getElementById('status').className = 'status running';
      isStopped = false;
      fetchAPI('start');
    }
    
    function updateKp() {
      const val = document.getElementById('kp').value;
      document.getElementById('kpVal').textContent = val;
      updateAll();
    }
    
    function updateKd() {
      const val = document.getElementById('kd').value;
      document.getElementById('kdVal').textContent = val;
      updateAll();
    }
    
    function updateSpeed() {
      const val = document.getElementById('sp').value;
      document.getElementById('spVal').textContent = val;
      updateAll();
    }
    
    function updateAll() {
      if (isStopped) {
        alert('⚠️ Démarre le robot d\'abord!');
        return;
      }
      const kp = document.getElementById('kp').value;
      const kd = document.getElementById('kd').value;
      const sp = document.getElementById('sp').value;
      fetchAPI('set?kp=' + kp + '&kd=' + kd + '&sp=' + sp);
    }
  </script>
</body></html>)rawliteral";
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

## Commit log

2026-04-13 Ajout de la version 1 du Robot
    [Robot001.stl]
2026-04-13 Revise README with project overview and details
    Updated the README to include project details, materials used, functionalities, and chassis information.
2026-04-13 Ajout de la version 2 du Robot
    [Robot002l.stl]
2026-04-15 Ajout de la version 4 du Robot
    [Robot004.stl]
2026-05-01 Implement WiFi and web server for robot control
    Added WiFi and web server functionality for remote control and monitoring of the line follower robot. Updated sensor readings and control parameters to be adjustable via a web interface.
2026-05-27 Code des missions 1 a 20
2026-05-27 Code des missions 21 et 22
2026-05-29 code de la mission 23
